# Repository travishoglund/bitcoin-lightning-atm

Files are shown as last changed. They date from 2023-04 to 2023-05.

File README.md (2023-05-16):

# bitcoin-lightning-atm

The purpose of this repo is to help you setup your own Bitcoin Lightning ATM.  Currently there are 3 different configurations as follows:

### Penny ATMs

Penny ATM

Penny LED

### Multi Coin ATM

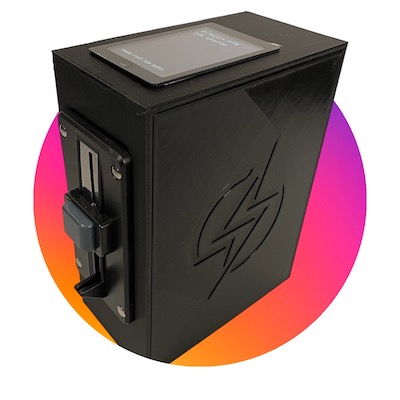
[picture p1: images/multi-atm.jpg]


# License
The code distributed and the product itself is GPLv3.  The purpose of this is to protect the community and ensure that any innovations will remain public under the following license agreements: 

1. Anyone can copy, modify and distribute this software.
2. You have to include the license and copyright notice with each and every distribution.
3. You can use this software privately.
4. You can use this software for commercial purposes.
5. If you dare build your business solely from this code, you risk open-sourcing the whole code base.
6. If you modify it, you have to indicate changes made to the code.
7. Any modifications of this code base MUST be distributed with the same license, GPLv3.
8. This software is provided without warranty.
9. The software author or license can not be held liable for any damages inflicted by the software.

More information about this license can be found [here](http://choosealicense.com/licenses/gpl-3.0/).

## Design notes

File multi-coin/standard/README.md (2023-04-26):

# Bitcoin Multi Coin ATM

#### This ATM can be built for about `$150 USD` in materials

Multi Coin ATM

`Pros`: Accepts multiple coins (setup for penny, nickel, dime, quarters)

`Cons`: Configuration of the coin acceptor takes more time

## Video Walkthrough
[https://www.youtube.com/watch?v=A0-by4YgqxY](https://www.youtube.com/watch?v=A0-by4YgqxY)

## Required Parts:

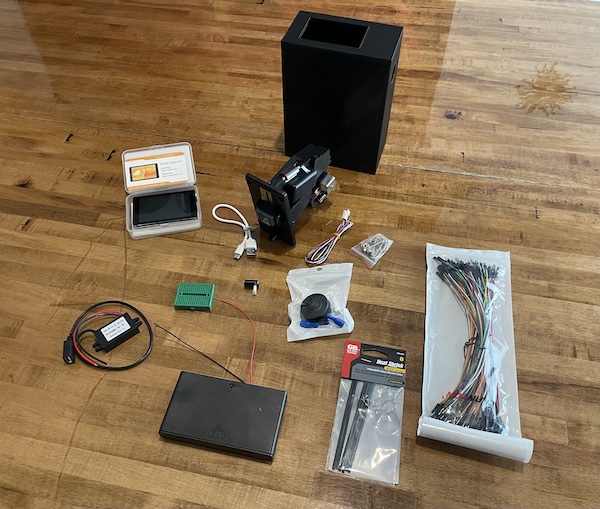
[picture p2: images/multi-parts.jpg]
Parts


- [Coin Acceptor](https://amzn.to/40fCalR)
- [ESP32 Micro Controller](https://amzn.to/40ixlse)
- [12V to 5V USB Adaptor](https://amzn.to/3L7NEUk)
- [12V Toggle Switch](https://amzn.to/3UNaFzg)
- [12V Battery Pack](https://amzn.to/3H1W39t)
- [Breadboard](https://amzn.to/40iYhb4)
- [10K Resister](https://amzn.to/40sGIFH)
- [Shrink Tubing](https://amzn.to/3ojl0H0)
- [Breadboard Jumper Wires](https://amzn.to/3GPbUIl)
- [AA Batteries x 8](https://amzn.to/41vrUqK)

## Recommended Tools

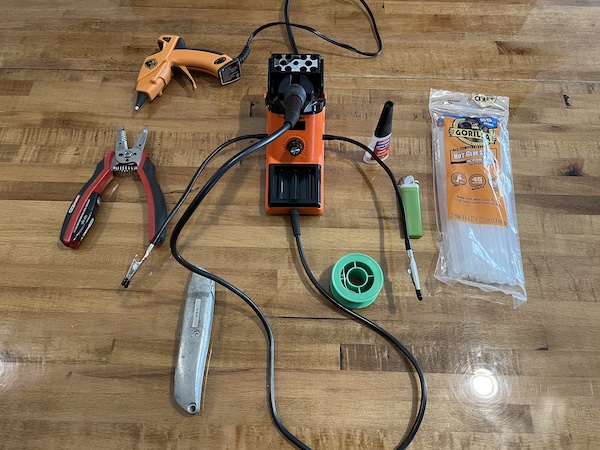
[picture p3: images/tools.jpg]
Tools


## Assembly Instructions

### Print the 3D parts
1. Print the [3D Box](../../3D/body.stl), then print the [Slotted Side Panel](../../3D/lid.stl).
   ####
   Printed Box

### LNBits Wallet Setup
- Go to [LNBits](https://legend.lnbits.com/) and create a wallet (give it whatever name you wish). Once created, it will show a warning that the wallet is only secured by this URL.  Copy the URL.  
- In the root of this project, go into the qrcodejs folder and open index.html.  Paste your wallet URL and it will generate a QR code for you to print.  I suggest taping this to the back of a post it note and putting it inside of your ATM for safekeeping. Deposit whatever you are comfortable with (I recommend 5,000 sats).
- `NOTE: This method of storing BTC is not secure and I only recommend putting 10,000 sats or less on this wallet just for demonstrating the functionality of the ATM to your friends/family on the go.  Keep your SATS safe at all times :)`
- Go to the extensions tab and add/enable "LNURLDevice", then click on it in the sidebar menu.
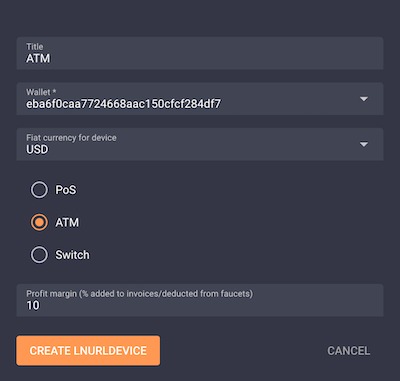
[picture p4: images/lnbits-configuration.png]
LNBits Configuration
- Enter in the following information.  
- On this screen, make sure to copy the id and key - we will use these in our code in the next section. LNBits Configuration

### Micro Controller Configuration
While that is printing, lets prepare the micro controller.
- Download the [Arduino IDE](https://www.arduino.cc/en/software)
- Once installed, connect the micro controller to your computer via USBC, and from the dropdown select "Select other board and port...", and select the "ESP32 Dev Module" and on the right select your USB port that it is connected to.
- Copy and paste the code from the arduino-code folder into the editor. Replace the "DEVICE_ID" with our id from the previous section, and "SECRET_CODE" with our key from the previous section.
- Click the upload button (the second button on the top left).  Once it uploads to the micro controller you should see the Bitcoin ATM screen.  It can safely be removed from the computer and is ready for the assembly into our box.

### Coin Acceptor Configuration
Next, we will configure the coin acceptor for USD currency. Connect the red and black wires from the coin acceptor to the battery bank respectively and load it with batteries. To configure the coin acceptor, follow the [manual](https://cdn.sparkfun.com/assets/7/a/b/a/4/DS-11719-Coin_Acceptor_-_Programmable__3_coin_types_.pdf).  Make sure to configure each coin for the correct number of pulses (1 - penny, 5 - nickel, 10 - dime, 25 - quarter).

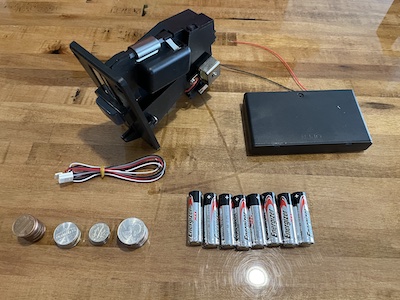
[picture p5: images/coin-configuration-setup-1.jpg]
Coin Configuration Setup
 Coin Configuration Setup Coin Configuration Setup

### Assembling the ATM
Now we get to put everything together and make this functional!

#### Assemble the LCD Screen
- Start by taking apart the LCD panel. There are tiny little tabs that lock into the metal plate so gently pry them until you can get the top and bottom separated.<br /> LCD Step 1
- Before assembling it into the ATM, ensure your printer made the LCD hole perfectly straight.  If necessary, shave the edges to be straight before inserting. Insert it through the top of the ATM at an angle.  Get the steel plate situated first, then place the top down on top of it.<br /> LCD Step 2
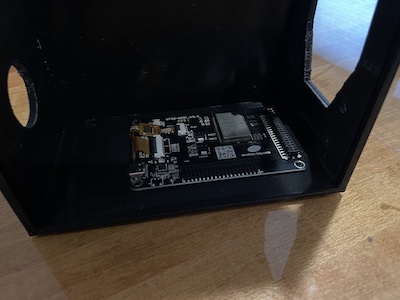
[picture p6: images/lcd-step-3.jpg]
LCD Step 3
- Flip the ATM upside down and press so it makes a tight fit.<br /> 
- Plug the USBC cable into the micro controller, then gently lift the cable and press it down with some hot glue (do not get it on the board).  This will hold the LCD firmly in place so it never wants to come apart.<br /> LCD Step 4

#### Assemble the Toggle Switch
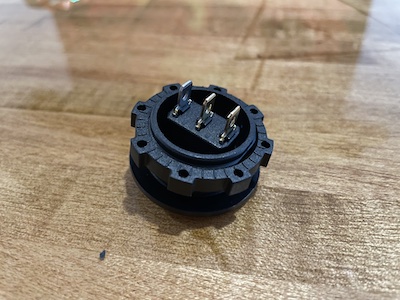
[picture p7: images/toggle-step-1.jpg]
Toggle Step 1
- On to the toggle switch! There are 3 pins on the toggle switch, the silver is the ground (black), and the two golds are power (red).<br /> 
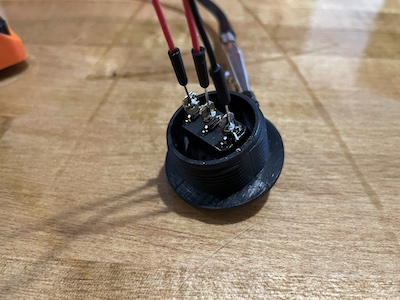
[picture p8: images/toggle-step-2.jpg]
Toggle Step 2
- Solder a black wire onto the silver pin, and two red wires on the gold pins.<br /> 
- Slide shrink tubing onto the wires and shrink them with a lighter.<br /> Toggle Step 3
- Smooth out the 3D hold with a utility knife and then slide the toggle switch into the device.<br /> Toggle Step 4
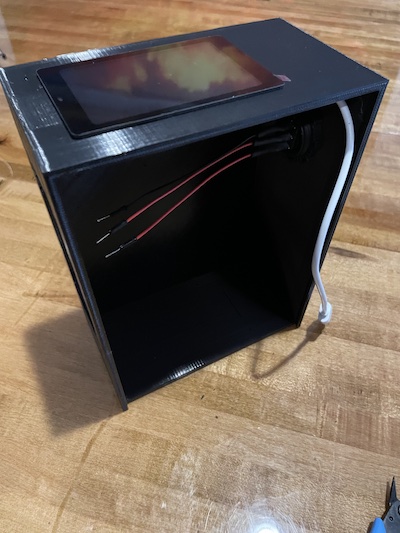
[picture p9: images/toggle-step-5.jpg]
Toggle Step 5
- Place the nut through the wires and spin it onto the toggle switch.  I prefer the LED of the toggle switch to be facing downward, but it doesn't really matter for functionality.<br /> 

#### Assemble the Coin Acceptor
- Plug the coin acceptor wires into the back of the device (snip the gray wires), and place it through the front of the box.  Secure it loosely with the top two bolts.<br /> Coin Acceptor Step 1
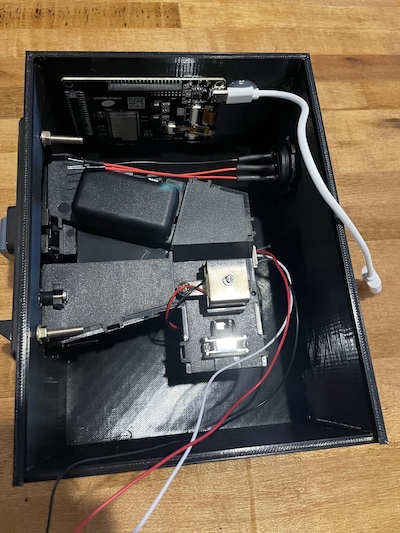
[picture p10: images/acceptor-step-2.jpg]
Coin Acceptor Step 2
- Secure the device with the bottom two bolts and tighten when everything aligns squarely on the front of the device.<br /> 

#### Assembling the Breadboard
- Prepare the breadboard by peeling off the sticky backing. <br /> Breadboard Step 1
- Place the breadboard in the upper right of the box.  You will want to place it so that all of the holes are accessible <br /> Breadboard Step 2

#### Connecting the 12V to 5V Power Adapter
- Prepare the 12V step down adapter, and grab some super glue or hot glue. <br /> 12V Step 1
- Apply some glue to the back of the adapter. <br /> 12V Step 2
- Orientation is important!  Place the adapter just below the toggle switch nut with the red and black wires facing the outside opening of the box.  The USB wire should naturally want to wrap around the toggle wires.  Make sure not to block the panel slot when fixing this to the box. <br /> 12V Step 3
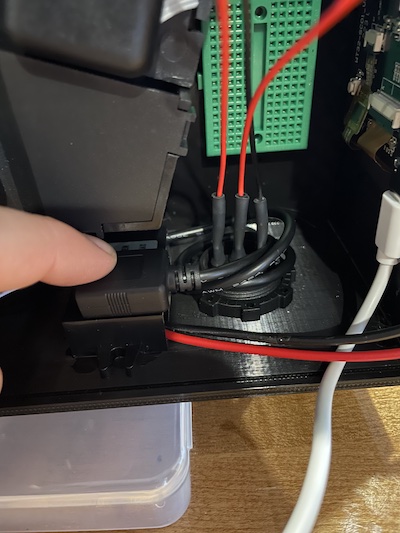
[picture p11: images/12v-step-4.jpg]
12V Step 4
- Wrap the excess USB wire around the toggle nut wires (2x) and then glue it to the top of the adapter box.  This holds everything nice and secure for us and still makes it accessible. <br /> 
- You can now plug in the white USB cable to the 12V adapter.

#### Wiring the device
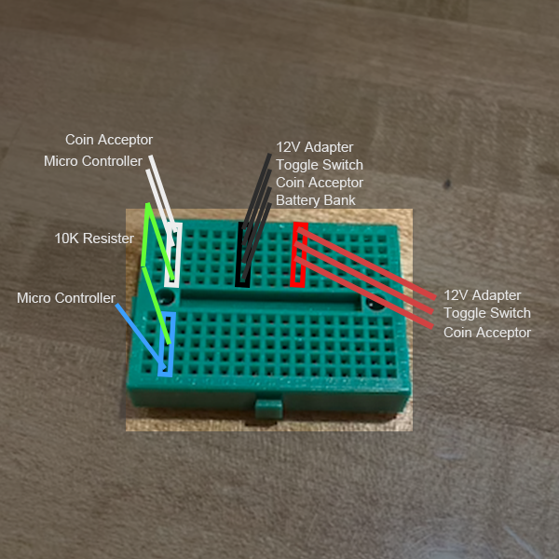
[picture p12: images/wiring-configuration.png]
Wiring Configuration 1
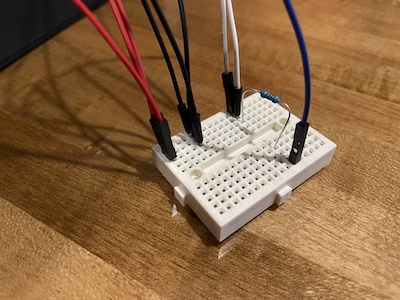
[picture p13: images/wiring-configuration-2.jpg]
Wiring Configuration 2
- The wiring it fairly straightforward, just make sure to save the red wire coming from the center pin of the toggle switch, as that will go directly to our battery bank.  Here is a couple images showcasing the wiring diagram. <br />  <br />  
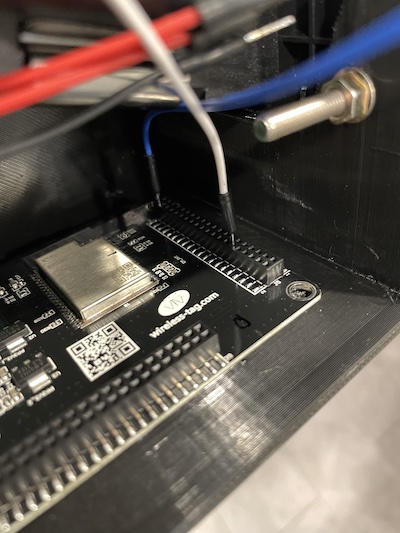
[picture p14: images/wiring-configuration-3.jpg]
Wiring Configuration 3
- Connect the white and blue wires to the micro controller.  The ATM is upside down in this picture - the white wire goes 6 holes in, and the blue wire is the last hole. <br /> .
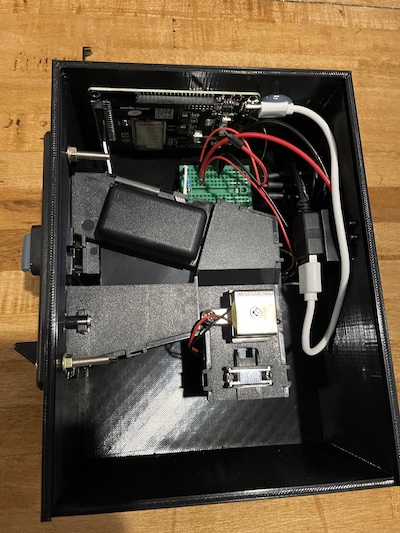
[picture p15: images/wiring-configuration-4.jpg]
Wiring Configuration 4
- When you are all finished wiring, it should look like this! <br />  

#### Connecting it to power
- Prepare the battery bank. Place shrink tubing over the red and black wires and then solder the red wire to the wire coming from the center toggle switch wire.  Connect a black wire to the breadboard and solder that to the battery bank black wire. <br /> Battery 1 
- Using a lighter, shrink the shrink tubing. <br /> Battery 2 
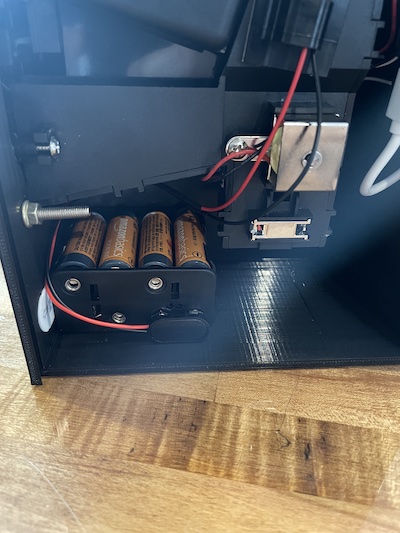
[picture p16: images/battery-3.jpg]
Battery 3
- Place a 3M strip to the side of the battery bank and press it against the front so we have plenty of room for our coins to drop into the ATM.  

#### Slide the Panel on
- Time to close this thing up and power it on! <br /> Final
- Here is our finished product.  Power it on and enjoy! <br /> Final 2

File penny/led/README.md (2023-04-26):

# Bitcoin Penny ATM (LED)

#### This ATM can be built for about `$150 USD` in materials

Penny LED ATM

`Pros`: Professional/Modern looking, save more of your SATS from sale

`Cons`: Only accepts a single coin as input (penny)

## Video Walkthrough
[https://www.youtube.com/watch?v=A0-by4YgqxY](https://www.youtube.com/watch?v=A0-by4YgqxY)

## Required Parts:

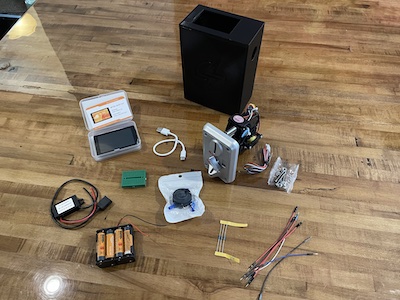
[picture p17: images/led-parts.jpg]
Parts


- [Coin Acceptor](https://amzn.to/421g9J6)
- [ESP32 Micro Controller](https://amzn.to/40ixlse)
- [12V to 5V USB Adaptor](https://amzn.to/3L7NEUk)
- [12V Toggle Switch](https://amzn.to/3UNaFzg)
- [12V Battery Pack](https://amzn.to/3H1W39t)
- [Breadboard](https://amzn.to/40iYhb4)
- [10K Resister](https://amzn.to/40sGIFH)
- [Shrink Tubing](https://amzn.to/3ojl0H0)
- [Breadboard Jumper Wires](https://amzn.to/3GPbUIl)
- [AA Batteries x 8](https://amzn.to/41vrUqK)

## Recommended Tools

Tools

## Assembly Instructions

### Print the 3D parts
1. Print the [3D Box](../../3D/body.stl), then print the [Slotted Side Panel](../../3D/lid.stl).
   ####
   Printed Box

### LNBits Wallet Setup
- Go to [LNBits](https://legend.lnbits.com/) and create a wallet (give it whatever name you wish). Once created, it will show a warning that the wallet is only secured by this URL.  Copy the URL.
- In the root of this project, go into the qrcodejs folder and open index.html.  Paste your wallet URL and it will generate a QR code for you to print.  I suggest taping this to the back of a post it note and putting it inside of your ATM for safekeeping. Deposit whatever you are comfortable with (I recommend 5,000 sats).
- `NOTE: This method of storing BTC is not secure and I only recommend putting 10,000 sats or less on this wallet just for demonstrating the functionality of the ATM to your friends/family on the go.  Keep your SATS safe at all times :)`
- Go to the extensions tab and add/enable "LNURLDevice", then click on it in the sidebar menu.
- Enter in the following information.  LNBits Configuration
- On this screen, make sure to copy the id and key - we will use these in our code in the next section. LNBits Configuration

### Micro Controller Configuration
While that is printing, lets prepare the micro controller.
- Download the [Arduino IDE](https://www.arduino.cc/en/software)
- Once installed, connect the micro controller to your computer via USBC, and from the dropdown select "Select other board and port...", and select the "ESP32 Dev Module" and on the right select your USB port that it is connected to.
- Copy and paste the code from the arduino-code folder into the editor. Replace the "DEVICE_ID" with our id from the previous section, and "SECRET_CODE" with our key from the previous section.
- Click the upload button (the second button on the top left).  Once it uploads to the micro controller you should see the Bitcoin ATM screen.  It can safely be removed from the computer and is ready for the assembly into our box.

### Coin Acceptor Configuration
On the side of the coin acceptor there is a slot for a coin to be added.  Slide the sample coin out and insert a penny into the slot - make sure it is seated securely.

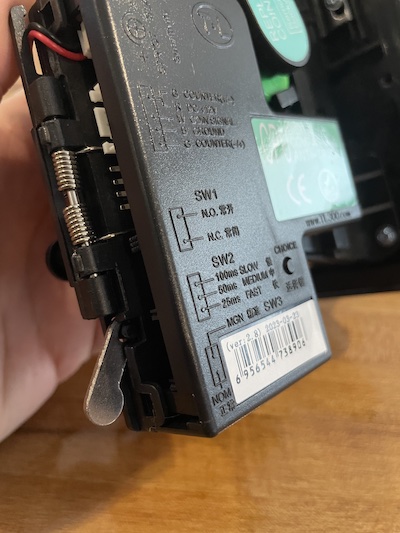
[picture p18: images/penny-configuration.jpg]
Coin Configuration


SW1 - N.O

SW2 - 50ms

SW3 - NOM

### Assembling the ATM
Now we get to put everything together and make this functional!

#### Assemble the LCD Screen
- Start by taking apart the LCD panel. There are tiny little tabs that lock into the metal plate so gently pry them until you can get the top and bottom separated.<br /> LCD Step 1
- Before assembling it into the ATM, ensure your printer made the LCD hole perfectly straight.  If necessary, shave the edges to be straight before inserting. Insert it through the top of the ATM at an angle.  Get the steel plate situated first, then place the top down on top of it.<br /> LCD Step 2
- Flip the ATM upside down and press so it makes a tight fit.<br /> LCD Step 3
- Plug the USBC cable into the micro controller, then gently lift the cable and press it down with some hot glue (do not get it on the board).  This will hold the LCD firmly in place so it never wants to come apart.<br /> LCD Step 4

#### Assemble the Toggle Switch
- On to the toggle switch! There are 3 pins on the toggle switch, the silver is the ground (black), and the two golds are power (red).<br /> Toggle Step 1
- Solder a black wire onto the silver pin, and two red wires on the gold pins.<br /> Toggle Step 2
- Slide shrink tubing onto the wires and shrink them with a lighter.<br /> Toggle Step 3
- Smooth out the 3D hold with a utility knife and then slide the toggle switch into the device.<br /> Toggle Step 4
- Place the nut through the wires and spin it onto the toggle switch.  I prefer the LED of the toggle switch to be facing downward, but it doesn't really matter for functionality.<br /> Toggle Step 5

#### Assemble the Coin Acceptor
- Plug the coin acceptor wires into the back of the device (snip the gray wires), and place it through the front of the box.  Secure it loosely with the top two bolts.<br /> Coin Acceptor Step 1
- Secure the device with the bottom two bolts and tighten when everything aligns squarely on the front of the device.<br /> Coin Acceptor Step 2

#### Assembling the Breadboard
- Prepare the breadboard by peeling off the sticky backing. <br /> Breadboard Step 1
- Place the breadboard in the upper right of the box.  You will want to place it so that all of the holes are accessible <br /> Breadboard Step 2

#### Connecting the 12V to 5V Power Adapter
- Prepare the 12V step down adapter, and grab some super glue or hot glue. <br /> 12V Step 1
- Apply some glue to the back of the adapter. <br /> 12V Step 2
- Orientation is important!  Place the adapter just below the toggle switch nut with the red and black wires facing the outside opening of the box.  The USB wire should naturally want to wrap around the toggle wires.  Make sure not to block the panel slot when fixing this to the box. <br /> 12V Step 3
- Wrap the excess USB wire around the toggle nut wires (2x) and then glue it to the top of the adapter box.  This holds everything nice and secure for us and still makes it accessible. <br /> 12V Step 4
- You can now plug in the white USB cable to the 12V adapter.

#### Wiring the device
- The wiring it fairly straightforward, just make sure to save the red wire coming from the center pin of the toggle switch, as that will go directly to our battery bank.  Here is a couple images showcasing the wiring diagram. <br /> Wiring Configuration 1 <br /> Wiring Configuration 2
- Connect the white and blue wires to the micro controller.  The ATM is upside down in this picture - the white wire goes 6 holes in, and the blue wire is the last hole. <br /> Wiring Configuration 3.
- When you are all finished wiring, it should look like this! <br /> Wiring Configuration 4

#### Connecting it to power
- Prepare the battery bank. Place shrink tubing over the red and black wires and then solder the red wire to the wire coming from the center toggle switch wire.  Connect a black wire to the breadboard and solder that to the battery bank black wire. <br /> Battery 1
- Using a lighter, shrink the shrink tubing. <br /> Battery 2
- Place a 3M strip to the side of the battery bank and press it against the front so we have plenty of room for our coins to drop into the ATM. Battery 3

#### Slide the Panel on @TODO
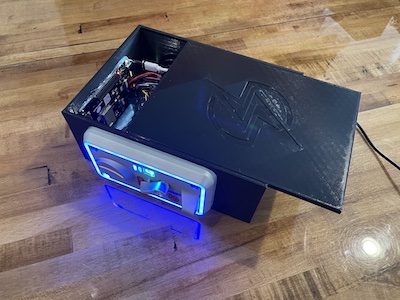
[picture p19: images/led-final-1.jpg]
Final
- Time to close this thing up and power it on! <br /> 
- Here is our finished product.  Power it on and enjoy! <br /> Final 2

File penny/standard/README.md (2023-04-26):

# Bitcoin Penny ATM

#### This ATM can be built for about `$125 USD` in materials

Penny LED ATM

`Pros`: Simple build, save more of your SATS from sale

`Cons`: Only accepts a single coin as input (penny)

## Video Walkthrough
[https://www.youtube.com/watch?v=A0-by4YgqxY](https://www.youtube.com/watch?v=A0-by4YgqxY)

## Required Parts:

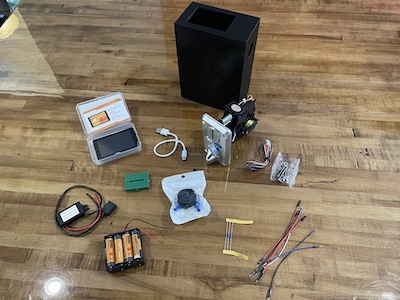
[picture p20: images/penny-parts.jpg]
Parts


- [Coin Acceptor](https://amzn.to/40AHUHj)
- [ESP32 Micro Controller](https://amzn.to/40ixlse)
- [12V to 5V USB Adaptor](https://amzn.to/3L7NEUk)
- [12V Toggle Switch](https://amzn.to/3UNaFzg)
- [12V Battery Pack](https://amzn.to/3H1W39t)
- [Breadboard](https://amzn.to/40iYhb4)
- [10K Resister](https://amzn.to/40sGIFH)
- [Shrink Tubing](https://amzn.to/3ojl0H0)
- [Breadboard Jumper Wires](https://amzn.to/3GPbUIl)
- [AA Batteries x 8](https://amzn.to/41vrUqK)

## Recommended Tools

Tools

## Assembly Instructions

### Print the 3D parts
1. Print the [3D Box](../../3D/body.stl), then print the [Slotted Side Panel](../../3D/lid.stl).
   ####
   Printed Box

### LNBits Wallet Setup
- Go to [LNBits](https://legend.lnbits.com/) and create a wallet (give it whatever name you wish). Once created, it will show a warning that the wallet is only secured by this URL.  Copy the URL.
- In the root of this project, go into the qrcodejs folder and open index.html.  Paste your wallet URL and it will generate a QR code for you to print.  I suggest taping this to the back of a post it note and putting it inside of your ATM for safekeeping. Deposit whatever you are comfortable with (I recommend 5,000 sats).
- `NOTE: This method of storing BTC is not secure and I only recommend putting 10,000 sats or less on this wallet just for demonstrating the functionality of the ATM to your friends/family on the go.  Keep your SATS safe at all times :)`
- Go to the extensions tab and add/enable "LNURLDevice", then click on it in the sidebar menu.
- Enter in the following information.  LNBits Configuration
- On this screen, make sure to copy the id and key - we will use these in our code in the next section. LNBits Configuration

### Micro Controller Configuration
While that is printing, lets prepare the micro controller.
- Download the [Arduino IDE](https://www.arduino.cc/en/software)
- Once installed, connect the micro controller to your computer via USBC, and from the dropdown select "Select other board and port...", and select the "ESP32 Dev Module" and on the right select your USB port that it is connected to.
- Copy and paste the code from the arduino-code folder into the editor. Replace the "DEVICE_ID" with our id from the previous section, and "SECRET_CODE" with our key from the previous section.
- Click the upload button (the second button on the top left).  Once it uploads to the micro controller you should see the Bitcoin ATM screen.  It can safely be removed from the computer and is ready for the assembly into our box.

### Coin Acceptor Configuration
On the side of the coin acceptor there is a slot for a coin to be added.  Slide the sample coin out and insert a penny into the slot - make sure it is seated securely.

Coin Configuration

SW1 - N.O

SW2 - 50ms

SW3 - NOM

### Assembling the ATM
Now we get to put everything together and make this functional!

#### Assemble the LCD Screen
- Start by taking apart the LCD panel. There are tiny little tabs that lock into the metal plate so gently pry them until you can get the top and bottom separated.<br /> LCD Step 1
- Before assembling it into the ATM, ensure your printer made the LCD hole perfectly straight.  If necessary, shave the edges to be straight before inserting. Insert it through the top of the ATM at an angle.  Get the steel plate situated first, then place the top down on top of it.<br /> LCD Step 2
- Flip the ATM upside down and press so it makes a tight fit.<br /> LCD Step 3
- Plug the USBC cable into the micro controller, then gently lift the cable and press it down with some hot glue (do not get it on the board).  This will hold the LCD firmly in place so it never wants to come apart.<br /> LCD Step 4

#### Assemble the Toggle Switch
- On to the toggle switch! There are 3 pins on the toggle switch, the silver is the ground (black), and the two golds are power (red).<br /> Toggle Step 1
- Solder a black wire onto the silver pin, and two red wires on the gold pins.<br /> Toggle Step 2
- Slide shrink tubing onto the wires and shrink them with a lighter.<br /> Toggle Step 3
- Smooth out the 3D hold with a utility knife and then slide the toggle switch into the device.<br /> Toggle Step 4
- Place the nut through the wires and spin it onto the toggle switch.  I prefer the LED of the toggle switch to be facing downward, but it doesn't really matter for functionality.<br /> Toggle Step 5

#### Assemble the Coin Acceptor
- Plug the coin acceptor wires into the back of the device (snip the gray wires), and place it through the front of the box.  Secure it loosely with the top two bolts.<br /> Coin Acceptor Step 1
- Secure the device with the bottom two bolts and tighten when everything aligns squarely on the front of the device.<br /> Coin Acceptor Step 2

#### Assembling the Breadboard
- Prepare the breadboard by peeling off the sticky backing. <br /> Breadboard Step 1
- Place the breadboard in the upper right of the box.  You will want to place it so that all of the holes are accessible <br /> Breadboard Step 2

#### Connecting the 12V to 5V Power Adapter
- Prepare the 12V step down adapter, and grab some super glue or hot glue. <br /> 12V Step 1
- Apply some glue to the back of the adapter. <br /> 12V Step 2
- Orientation is important!  Place the adapter just below the toggle switch nut with the red and black wires facing the outside opening of the box.  The USB wire should naturally want to wrap around the toggle wires.  Make sure not to block the panel slot when fixing this to the box. <br /> 12V Step 3
- Wrap the excess USB wire around the toggle nut wires (2x) and then glue it to the top of the adapter box.  This holds everything nice and secure for us and still makes it accessible. <br /> 12V Step 4
- You can now plug in the white USB cable to the 12V adapter.

#### Wiring the device
- The wiring it fairly straightforward, just make sure to save the red wire coming from the center pin of the toggle switch, as that will go directly to our battery bank.  Here is a couple images showcasing the wiring diagram. <br /> Wiring Configuration 1 <br /> Wiring Configuration 2
- Connect the white and blue wires to the micro controller.  The ATM is upside down in this picture - the white wire goes 6 holes in, and the blue wire is the last hole. <br /> Wiring Configuration 3.
- When you are all finished wiring, it should look like this! <br /> Wiring Configuration 4

#### Connecting it to power
- Prepare the battery bank. Place shrink tubing over the red and black wires and then solder the red wire to the wire coming from the center toggle switch wire.  Connect a black wire to the breadboard and solder that to the battery bank black wire. <br /> Battery 1
- Using a lighter, shrink the shrink tubing. <br /> Battery 2
- Place a 3M strip to the side of the battery bank and press it against the front so we have plenty of room for our coins to drop into the ATM. Battery 3

#### Slide the Panel on
- Time to close this thing up and power it on! <br /> Final
- Here is our finished product.  Power it on and enjoy! <br /> Final 2

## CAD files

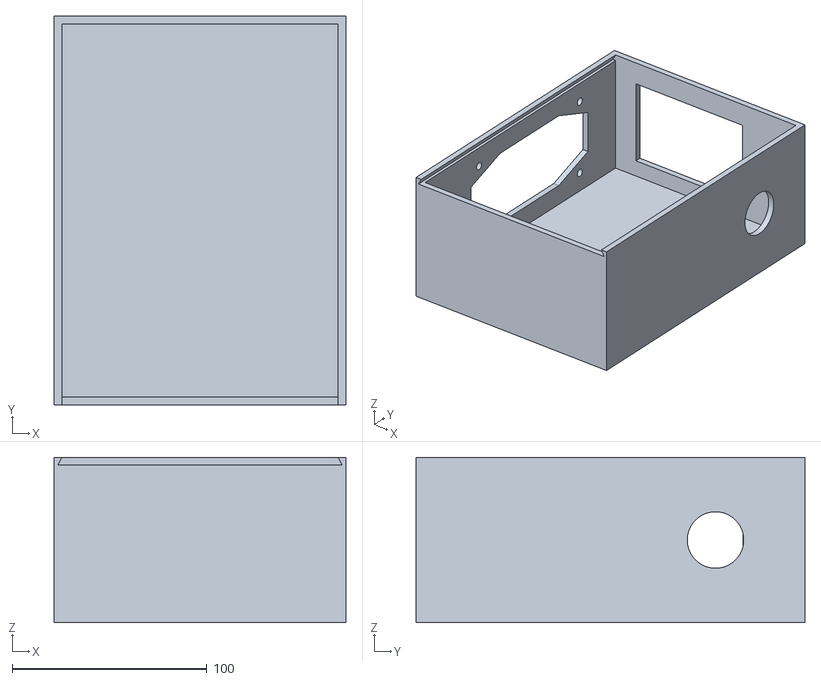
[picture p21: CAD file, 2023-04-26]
3D/body.stl
150.0 x 200.0 x 85.0

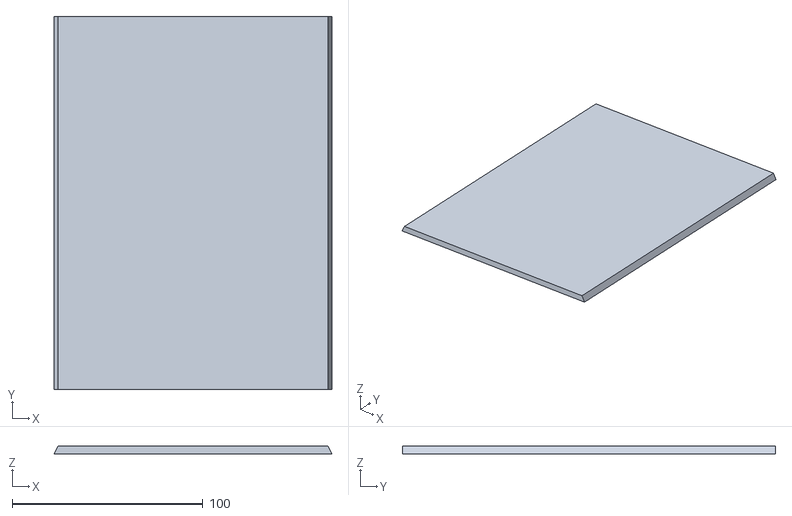
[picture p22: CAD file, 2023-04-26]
3D/lid.stl
145.9 x 196.0 x 3.97

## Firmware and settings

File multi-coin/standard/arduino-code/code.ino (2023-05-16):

#include <Hash.h>
#include "qrcoded.h"
#include "Bitcoin.h"
#include <TFT_eSPI.h>
#include <JC_Button.h>
#define BTN1 39 // Screen tap button

// LNURLDevices ATM details - edit these as needed
String baseURLATM = "https://legend.lnbits.com/lnurldevice/api/v1/lnurl/DEVICE_ID";
String secretATM = "SECRET";
String currencyATM = "USD";
float coinValues[4] = {0.01, 0.05, 0.1, 0.25};
int charge = 10; // % you will charge people for service, set in LNbits extension
float maxAmount = 5.00; // max amount per withdraw

// Program Variables - do not change these
int impulseCount = 0;
unsigned long lastInterrupt;
String qrData;
float total;

// LCD Display & Clicking Settings
TFT_eSPI tft = TFT_eSPI();
Button BTNA(BTN1);

void setup() {
  // Initialize LCD Screen
  BTNA.begin();
  tft.init();
  tft.setRotation(2);
  tft.invertDisplay(false);
  showATMStartScreen();

  // Listen for coin insertions on Pin 2, and track latest interrupt
  Serial.begin(9600);
  attachInterrupt(digitalPinToInterrupt(2), coinInterrupt, FALLING);
  lastInterrupt = millis();
}

void loop() {

  // Identified the coin by number of pulses
  if(impulseCount > 0 && (millis() - lastInterrupt > 1000)) {
    total = total + coinValues[impulseCount - 2]; // Pulses start at 2 for pennies, array starts at 0
    impulseCount = 0;
    showATMDepositScreen();
  }

  // When button is pushed, show the QR code for redemption
  BTNA.read();
  if((total > 0 && BTNA.wasReleased()) || total == maxAmount) {
    makeLNURL();
    showATMRedemptionScreen("SCAN, THEN TAP WHEN FINISHED");
  }

}

/*
 * Triggered when voltage changes on Pin 2
 */
void coinInterrupt() {
  impulseCount = impulseCount + 1;
  lastInterrupt = millis();
}

/*
 * Prints out our basic UI
 */
void printMessage(String text1, String text2, String text3, int ftcolor, int bgcolor)
{
  tft.fillScreen(bgcolor);
  tft.setTextColor(ftcolor, bgcolor);
  tft.setTextSize(3);
  tft.setCursor(24, 30);
  tft.println(text1);
  tft.setCursor(24, 70);
  tft.println(text2);
  tft.setCursor(24, 420);
  tft.setTextSize(2);
  tft.println(text3);
}

/*
 * The first screen for our Bitcoin ATM - this welcomes the user
 */
void showATMStartScreen() {
  total = 0;
  tft.fillScreen(TFT_BLACK);

  printMessage("Bitcoin ATM", String(charge) + "% charge (" + currencyATM + ")", "TRADE FIAT FOR SATS!", TFT_WHITE, TFT_BLACK);
}

/*
 * The second screen for our Bitcoin ATM - this shows the users deposited funds
 */
void showATMDepositScreen() {
  printMessage("Bitcoin ATM", "Total: " + String(total) + " " + currencyATM, "TAP SCREEN WHEN FINISHED", TFT_WHITE, TFT_BLACK);
}

/*
 * The final screen shows our QR code once user deposits are finished, pre-signed to be redeemed on Lightning
 */
void showATMRedemptionScreen(String message)
{
  tft.fillScreen(TFT_WHITE);
  qrData.toUpperCase();
  const char *qrDataChar = qrData.c_str();
  QRCode qrcoded;
  uint8_t qrcodeData[qrcode_getBufferSize(20)];
  qrcode_initText(&qrcoded, qrcodeData, 11, 0, qrDataChar);

  for (uint8_t y = 0; y < qrcoded.size; y++)
  {
    for (uint8_t x = 0; x < qrcoded.size; x++)
    {
      if (qrcode_getModule(&qrcoded, x, y))
      {
        tft.fillRect(40 + 4 * x, 40 + 4 * y, 4, 4, TFT_BLACK);
      }
      else
      {
        tft.fillRect(40 + 4 * x, 40 + 4 * y, 4, 4, TFT_WHITE);
      }
    }
  }

  tft.setCursor(60, 420);
  tft.setTextSize(1);
  tft.setTextColor(TFT_BLACK, TFT_WHITE);
  tft.println(message);

  bool waitForTap = true;
  while(waitForTap){
    BTNA.read();
    if (BTNA.wasReleased()) {
      waitForTap = false;
      showATMStartScreen();
    }
  }
}

////////////////////////////////////////////
///////////////LNURL STUFF//////////////////
////USING STEPAN SNIGREVS GREAT CRYTPO//////
////////////THANK YOU STEPAN////////////////
////////////////////////////////////////////

void to_upper(char *arr)
{
  for (size_t i = 0; i < strlen(arr); i++)
  {
    if (arr[i] >= 'a' && arr[i] <= 'z')
    {
      arr[i] = arr[i] - 'a' + 'A';
    }
  }
}

void makeLNURL()
{
  int randomPin = random(1000, 9999);
  byte nonce[8];
  for (int i = 0; i < 8; i++)
  {
    nonce[i] = random(256);
  }

  byte payload[51]; // 51 bytes is max one can get with xor-encryption

    size_t payload_len = xor_encrypt(payload, sizeof(payload), (uint8_t *)secretATM.c_str(), secretATM.length(), nonce, sizeof(nonce), randomPin, float(total * 100));
    String preparedURL = baseURLATM + "?atm=1&p=";
    preparedURL += toBase64(payload, payload_len, BASE64_URLSAFE | BASE64_NOPADDING);

  Serial.println(preparedURL);
  char Buf[200];
  preparedURL.toCharArray(Buf, 200);
  char *url = Buf;
  byte *data = (byte *)calloc(strlen(url) * 2, sizeof(byte));
  size_t len = 0;
  int res = convert_bits(data, &len, 5, (byte *) url, strlen(url), 8, 1);
  char *charLnurl = (char *) calloc(strlen(url) * 2, sizeof(byte));
  bech32_encode(charLnurl, "lnurl", data, len);
  to_upper(charLnurl);
  qrData = charLnurl;
  Serial.println(charLnurl);
}

int xor_encrypt(uint8_t *output, size_t outlen, uint8_t *key, size_t keylen, uint8_t *nonce, size_t nonce_len, uint64_t pin, uint64_t amount_in_cents)
{
  // check we have space for all the data:
  // <variant_byte><len|nonce><len|payload:{pin}{amount}><hmac>
  if (outlen < 2 + nonce_len + 1 + lenVarInt(pin) + 1 + lenVarInt(amount_in_cents) + 8)
  {
    return 0;
  }

  int cur = 0;
  output[cur] = 1; // variant: XOR encryption
  cur++;

  // nonce_len | nonce
  output[cur] = nonce_len;
  cur++;
  memcpy(output + cur, nonce, nonce_len);
  cur += nonce_len;

  // payload, unxored first - <pin><currency byte><amount>
  int payload_len = lenVarInt(pin) + 1 + lenVarInt(amount_in_cents);
  output[cur] = (uint8_t)payload_len;
  cur++;
  uint8_t *payload = output + cur;                                 // pointer to the start of the payload
  cur += writeVarInt(pin, output + cur, outlen - cur);             // pin code
  cur += writeVarInt(amount_in_cents, output + cur, outlen - cur); // amount
  cur++;

  // xor it with round key
  uint8_t hmacresult[32];
  SHA256 h;
  h.beginHMAC(key, keylen);
  h.write((uint8_t *) "Round secret:", 13);
  h.write(nonce, nonce_len);
  h.endHMAC(hmacresult);
  for (int i = 0; i < payload_len; i++)
  {
    payload[i] = payload[i] ^ hmacresult[i];
  }

  // add hmac to authenticate
  h.beginHMAC(key, keylen);
  h.write((uint8_t *) "Data:", 5);
  h.write(output, cur);
  h.endHMAC(hmacresult);
  memcpy(output + cur, hmacresult, 8);
  cur += 8;

  // return number of bytes written to the output
  return cur;
}
